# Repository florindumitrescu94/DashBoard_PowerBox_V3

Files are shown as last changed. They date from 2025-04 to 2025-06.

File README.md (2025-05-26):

# DashBoard PowerBox V3 

The third evolution of the DashBoard PowerBox project, upgraded based on personal experiences and others' suggestion.
It incorporates the same basic construction as the V2 box, with easily sourceable components, but adds a few new elements. 

## Separate DC Port control
This box is now capable of controling separate DC ports, with 3 of them having their own separate switches and another 2 linked to the same switch. 

## Always On DC Port
Also, I've included an "Always On" port, which passes through the current and voltage meters, so its' power consumption will be taken into account. 

## Isolated external control
I've added two optocouplers which can be used to control external equipment (see explanation below). Using optocouplers ensures good insulation between the Arduino and the external equipment, so that a malfunction of one does not affect the other. This feature will allow the control of external non-ASCOM connected equipment, like relays or other types of switches to control devices around the observatory. The case was not designed to incorporate any connectors for the External switches, but a 3.5mm mono audio jack is recommended. 

## PWM Automation based on ambiental condition without temperature probes
I've removed the two temperature probe leads, as, based on personal experience, I rarely used them and they seemd hit or miss. Now, the automation of the dew heaters is done based on temperature and dew point. (Using the dedicated Control Center app, you can set three levels of agressivity for the PWM automation. In NINA/APT, this automation is fixed on the "Mid" level.



## Dedicated Control Center App
You can now control the power box through a dedicated app, built to interface with the ASCOM Driver. This allows you to use the power box without using NINA or other sequencer software. This could be useful in case you want to use planetary imaging software, like SharpCap, which, usually, do not have any Switch control module. Also, inside the Control Center, you can toggle the automatic PWM function for each output separately and you can control the aggresivity of the Auto PWM in 3 steps. 


## Ability to rename each port
When opening the Setup Dialog, you can rename any PWM, DC or EXT port, so you can keep track of which port each device is plugged in.

## Choose what happens when you disconnect from the device
Iside the Setup Dialog, you can choose to keep the ports on or turn them off when disconnecting. There are three options, one for the DC ports, one for the External ports and one for the PWM ports. 

## Carry over port state settings between control computers
On disconnect, the Arduino will store the ports state inside the EEPROM and will retreive them when the device is reinitiated. 

## Improved case design
The case has been redesigned for easier assembly and mounting options. It now has a 1/4 20 photo thread built into the base and the screws that keep the box closed have been now relocated to the top of the lid, instead of on its' side. The walls of the case have been improved, as well, now being thicker and stronger. The case now sports labels for each input and output and little holes for LEDs under each DC Port, to easily identify if power is applied to the port. 

## Improved power efficiency
The circuit has, also, been redesigned to accomodate more switches and, in doing so, the switching MOSFETs have been updated to a more efficient version. The IRF5305 MOSFETS used in the V2 box have a Drain to Source resistance of 60mOhms when fully on (Resistance provided by the datasheet, with Vgs = 10V). I've now switched to using SUD50P04 MOSFETS, which have only 7.5 - to 10 mOhms (provided by datasheet, measured at Vgs = 10V, with Id = 24A). This will ensure very low losses through the circuit, even at high current draw. Each MOSFET is capable of sustaining 40A of current, however, each DC port is limited by a resettable fuse to 5 Amps, which should be plenty for most astro equipment. There is also an internal, alwasy on, unfused 12V connector, in case you might want to extract a 12V supply inside the box, for a small step-up/step-down converter for other accesories. 





All the extra complexity has increased the power boxes' size, from 80 x 55 to 100 x 80, but it is still keeping a small enough size to be easily mounted on any telescope. 

NOTE: When building the box, you can add a capacitor between the RST and GND pins of the Arduino, in order to keep it from resetting when connecting to the computer. If you do this, when programming the device, you will need to press the Reset button on the arduino when the IDE will get to the "Uploading" step.

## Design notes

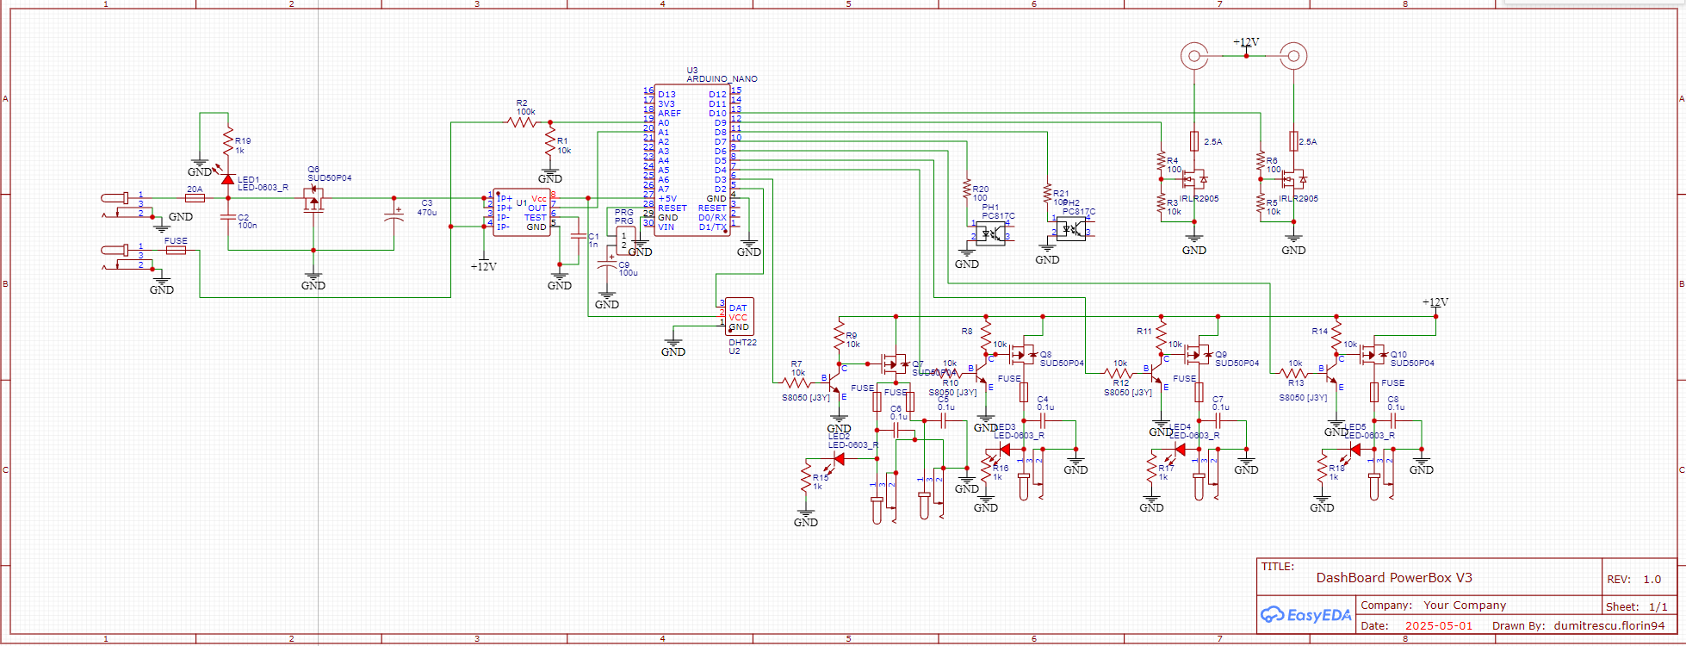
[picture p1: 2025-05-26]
Construction/schematic.png

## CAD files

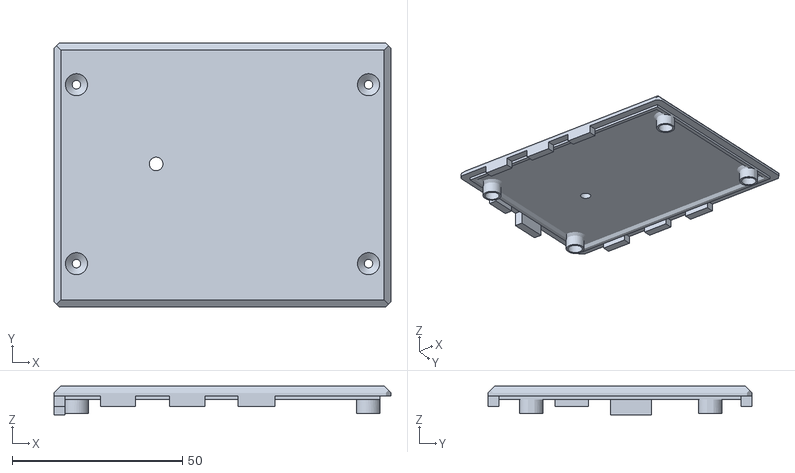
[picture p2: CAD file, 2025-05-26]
Construction/model/Cap.stl
99.0 x 77.5 x 8.50

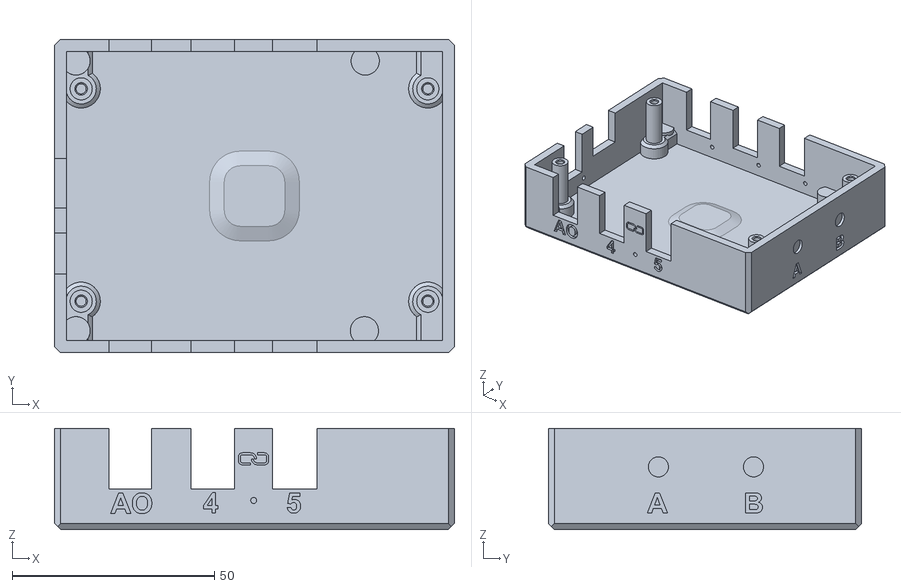
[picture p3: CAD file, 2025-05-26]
Construction/model/Body.stl
99.0 x 77.5 x 25.0

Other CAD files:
Construction/model/DashBoard_PowerBox_V3 v6.f3d
Construction/model/DashBoard_PowerBox_V3.f3d

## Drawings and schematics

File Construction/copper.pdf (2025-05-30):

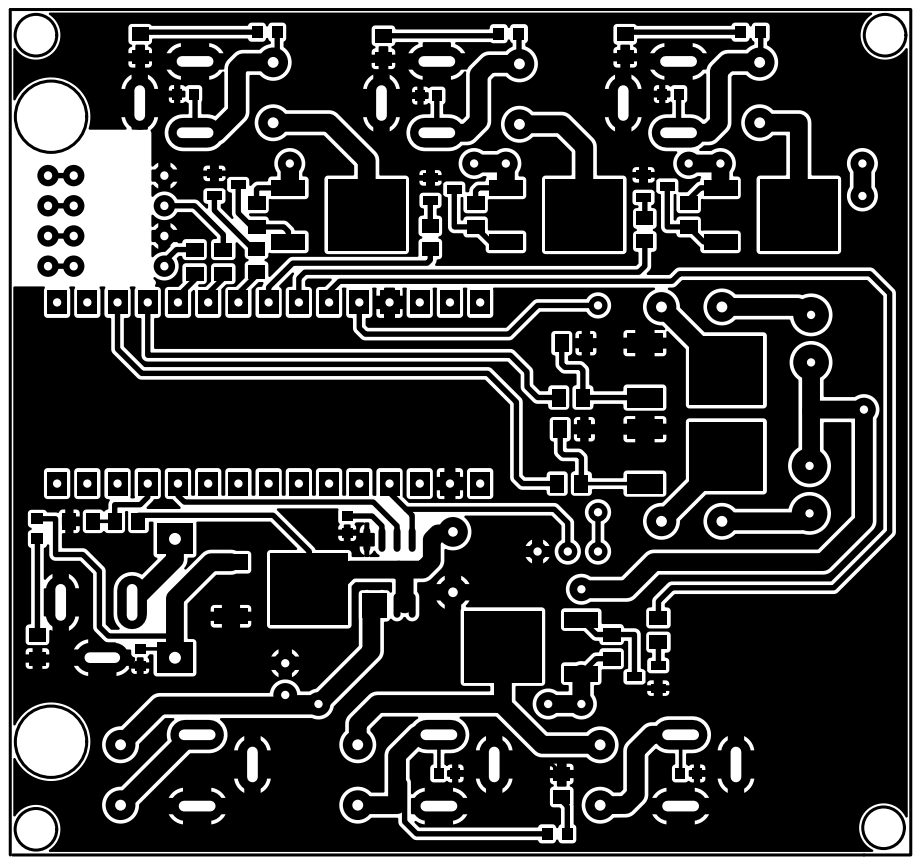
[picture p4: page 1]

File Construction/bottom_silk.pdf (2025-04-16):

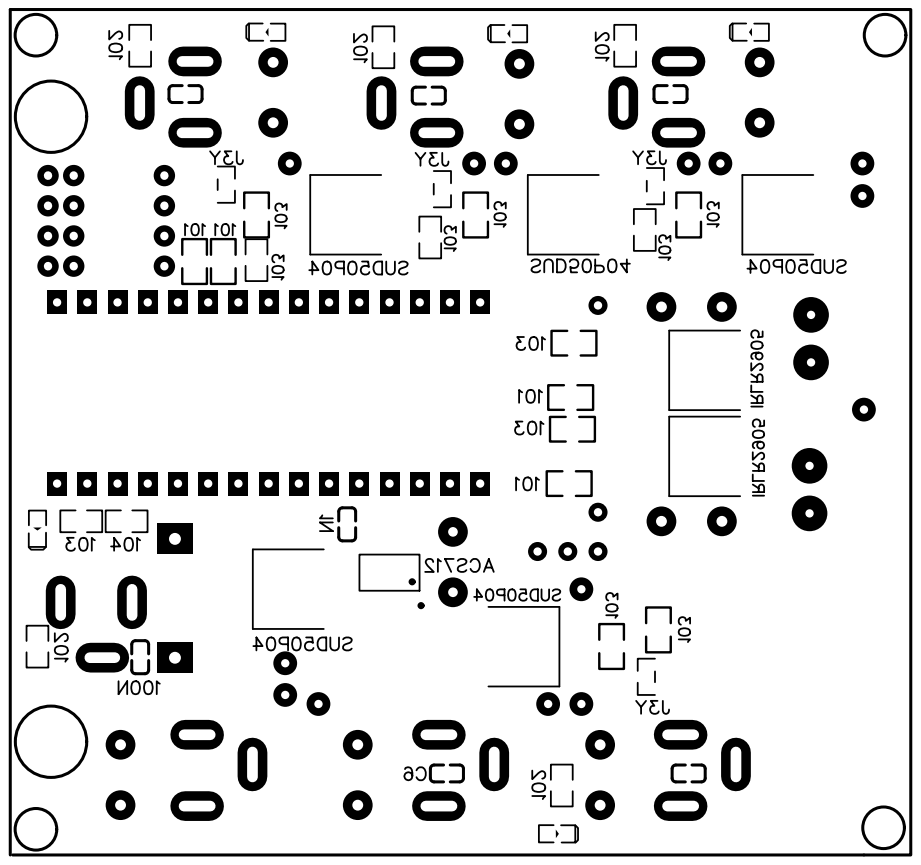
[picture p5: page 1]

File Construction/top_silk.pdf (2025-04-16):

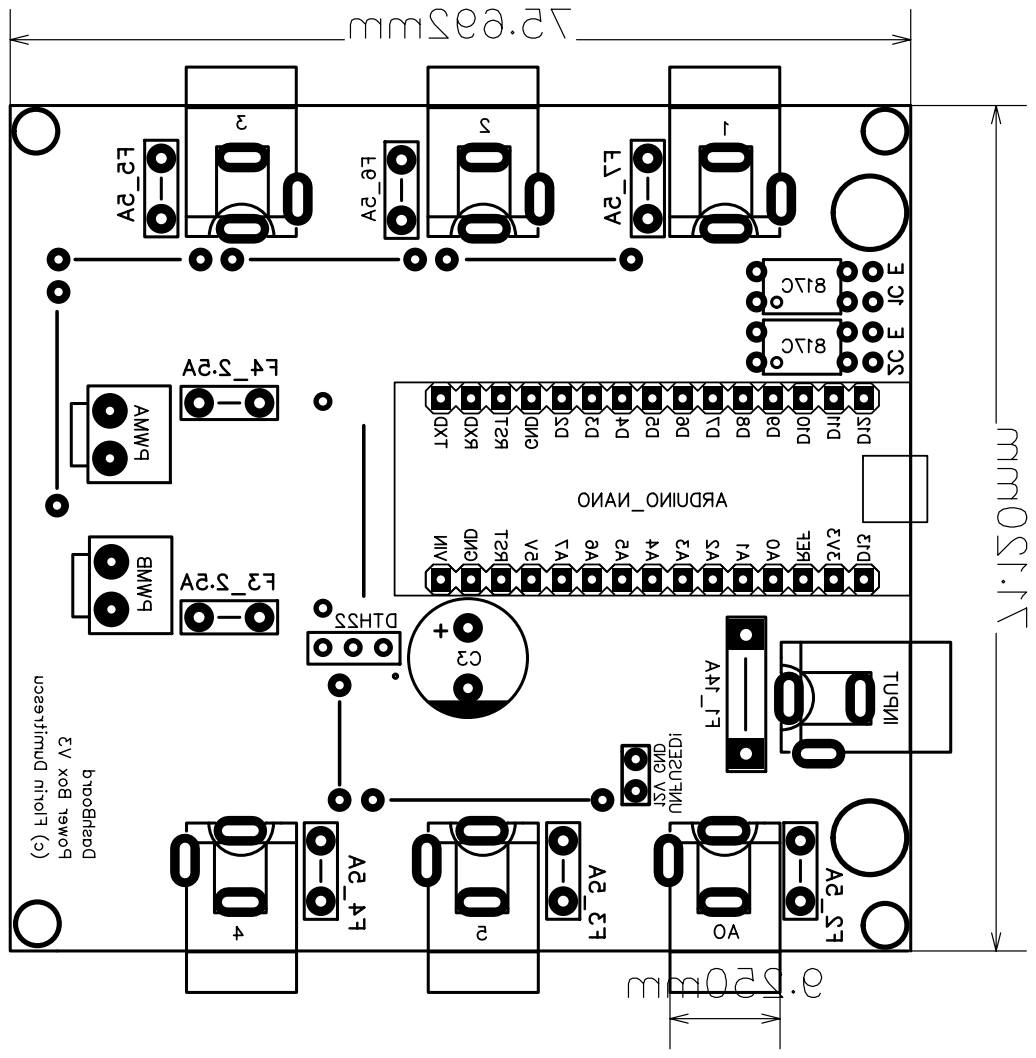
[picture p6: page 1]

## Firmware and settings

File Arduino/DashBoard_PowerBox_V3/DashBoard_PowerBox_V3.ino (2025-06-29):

/* Written by: Florin Dumitrescu
 *  for ascom_powerbox_and_ambientconditions built with
 *  Arduino NANO V3
 *  January 2024
 *  DashBoard Arduino code
 */
//INCLUDE LIBRARIES

#include <DHTStable.h>;
#include <EEPROM.h>;
DHTStable DHT;





//CODE VARIABLES
int DC1=0;
int DC2=0;
int DC3=0;
int DC45=0;
int EXT1=0;
int EXT2=0;
int PWM1=0;
int PWM2=0;
int level_a = 15; // MID by default
int level_b = 15; // MID by default
int levela_show = 1;
int levelb_show = 1;
int PWM_AUTO_A = 0;
int PWM_AUTO_B = 0;
float TEMP = 0.0;
int HUM_REL = 0;
float DEWPOINT = 0.0;
float DP_OFFSET = 2;
float VOLT = 0.00;
float VOLT_TEMP = 0.00;
int PIN_VALUE_A = 0;
int PIN_VALUE_V = 0;
float CURRENT_SAMPLE_SUM = 0.0;
int AVERAGE_COUNT = 0;
float AMP_AVERAGE[150];
float AVGAMP;
float AMP = 0.00;
float PWR = 0.00;
long int time1=0;
long int time2=0;
double PWR_TOTAL_S=0.00;
float PWR_TOTAL=0.00;
double ACS_resolution;


//VARIABLES FOR SERIALQUEUE
#define QUEUELENGTH         10             // number of commands that can be saved in the serial queue
#define MAXCOMMAND          42            // max length of a command
#define EOFSTR              '\n'
#define EOCOMMAND           '#'           // defines the end character of a command
#define SOCOMMAND           '>'           // defines the start character of a command
#define REFRESH             200           // read values every REFRESH milliseconds
#define PWMREFRESH          1000        // adjust PWM every 60 seconds
char* queue[QUEUELENGTH];
int queueHead = -1;
int queueCount = 0;
enum FSMStates { stateIdle, stateNtc, statePower, stateAutoPWM };
int idx = 0;                              // index into the command string
long int now;                             // now time in millis
long int last;                            // last time in millis
long int lastm;                           // last time we updated the dewheaters in millis
String line;                              // command buffer


//CHANGE ACS_VARIANT WITH YOUR ACS CHIP VARIANT (5A, 20A, 30A)
const int ACS_Variant = 20; //A
//PINS
const int DC1_PIN = 4 ;
const int DC2_PIN = 5;
const int DC3_PIN = 6;
const int DC45_PIN = 3;
const int EXT1_PIN = 7;
const int EXT2_PIN = 8;
const int PWM1_PIN = 10;
const int PWM2_PIN = 9;
const int DHT22_DATA = 2;
const int VM = A0;
const int AM = A1;


//-----------------------------------------------------------------------
// Utility functions
//-----------------------------------------------------------------------

char* pop() {
  --queueCount;
  return queue[queueHead--];
}


void push(char command[MAXCOMMAND]) {
  queueCount++;
  queueHead++;
  strncpy(queue[queueHead], command, MAXCOMMAND);
}


//ARDUINO INITIALIZATION
void setup()
{
  //SET PIN MODES
    pinMode(DC1_PIN, OUTPUT);
    pinMode(DC2_PIN, OUTPUT);
    pinMode(DC3_PIN, OUTPUT);
    pinMode(DC45_PIN, OUTPUT);
    pinMode(PWM1_PIN, OUTPUT);
    pinMode(PWM2_PIN, OUTPUT);
    pinMode(EXT1_PIN, OUTPUT);
    pinMode(EXT2_PIN, OUTPUT);
    pinMode(DHT22_DATA, INPUT);
    pinMode(VM, INPUT);
    pinMode(AM, INPUT);


  //INITIALIZE PIN STATE FROM EEPROM
   //
   if (EEPROM.read(40) != 255)
   // eerpom initializes with 255 on all values on a fresh arduino. That throws off ASCOM driver. 
   //To fix this, we check address 40 to see if it is 255. That means this is a first boot for the arduino. 
   //It skips the values, setting them to 0 as in the variable declaration step.
   //We then set the address 40 to 1 so that next time, we know it is not a first run and the EEPROM can be read
   {
    DC1=EEPROM.read(3);
    DC2=EEPROM.read(4);
    DC3=EEPROM.read(5);
    DC45=EEPROM.read(6);
    EXT1=EEPROM.read(7);
    EXT2=EEPROM.read(8);
    level_a=EEPROM.read(9);
    level_b=EEPROM.read(10);
    PWM1=EEPROM.read(1);
    PWM2=EEPROM.read(2);
   }
   EEPROM.update(40,1);//on first run on a fresh arduino, update address 40 to 1, so it will run the eeprom reads
    digitalWrite(DC1_PIN,DC1);
    digitalWrite(DC2_PIN,DC2);
    digitalWrite(DC3_PIN,DC3);
    digitalWrite(DC45_PIN,DC45);
    digitalWrite(EXT1_PIN,EXT1);
    digitalWrite(EXT2_PIN,EXT2);
    analogWrite(PWM1_PIN,PWM1);
    analogWrite(PWM2_PIN,PWM2);

    for ( int i=0; i < QUEUELENGTH; i++)
      queue[i] = (char*)malloc(MAXCOMMAND);
    line.reserve(MAXCOMMAND);
    
    Serial.begin(115200);
    Serial.flush();

    switch (ACS_Variant){
      case 5: 
        ACS_resolution = 0.185;
        break;
      case 20: 
        ACS_resolution = 0.100;
        break;
      case 30:
        ACS_resolution = 0.066;
        break;
    }
    // initialize our delays
    now = millis();
    last = now;
    lastm = now;
}

void clearSerialPort() {
  while ( Serial.available() )
    Serial.read();
}

// SerialEvent occurs whenever new data comes in the serial RX.
// you should really consider a start of command character.
void serialEvent() {

  // '#' ends the command, do not store these in the command buffer
  // read the command until the terminating # character
  char buf[MAXCOMMAND];
  while ( Serial.available() )
  {
    char inChar = Serial.read();
    switch ( inChar )
    {
      case '>':     // soc, reinit line
        // memset(line, 0, MAXCOMMAND);
        line = "";
        idx = 0;
        break;
      case '#':     // eoc
        line.toCharArray(buf, MAXCOMMAND);
        idx = 0;
        push(buf);
        break;
      default:      // anything else
        if ( idx < MAXCOMMAND - 1) {
          line += inChar;
        }
        break;
    }
  }
}


void processSerialCommand() {
  // this should never happen
  if ( queueCount == 0 )
    return;

  String cmd = String(pop());


//READS AND EXECUTES SERIAL COMMANDS FROM ASCOM DRIVER
  if (cmd.substring(0,6) == "SETDC1") SET_DC_PIN(1,(cmd.substring((cmd.indexOf('_')+1),cmd.indexOf('_')+2)).toInt()); 
  else if (cmd.substring(0,6) == "SETDC2") SET_DC_PIN(2,(cmd.substring((cmd.indexOf('_')+1),cmd.indexOf('_')+2)).toInt());
  else if (cmd.substring(0,6) == "SETDC3") SET_DC_PIN(3,(cmd.substring((cmd.indexOf('_')+1),cmd.indexOf('_')+2)).toInt()); 
  else if (cmd.substring(0,6) == "SETDC4") SET_DC_PIN(4,(cmd.substring((cmd.indexOf('_')+1),cmd.indexOf('_')+2)).toInt());  
  else if (cmd.substring(0,7) == "SETEXT1") SET_EXT_PIN(1,(cmd.substring((cmd.indexOf('_')+1),cmd.indexOf('_')+2)).toInt()); 
  else if (cmd.substring(0,7) == "SETEXT2") SET_EXT_PIN(2,(cmd.substring((cmd.indexOf('_')+1),cmd.indexOf('_')+2)).toInt()); 
  else if (cmd == "SETAUTOPWMA_1") {
      PWM_AUTO_A = 1;
  }
  else if (cmd == "SETAUTOPWMA_0") {
    PWM_AUTO_A = 0;
  }
  else if (cmd == "SETAUTOPWMB_1") {
      PWM_AUTO_B = 1;
  }
  else if (cmd == "SETAUTOPWMB_0") {
    PWM_AUTO_B = 0;
  }
  else if (cmd.substring(0,9) == "SETLEVELA") {SET_LEVEL(1,(cmd.substring((cmd.indexOf('_')+1),cmd.indexOf('_')+2)).toInt()); EEPROM.update(9,level_a);}
  else if (cmd.substring(0,9) == "SETLEVELB") {SET_LEVEL(2,(cmd.substring((cmd.indexOf('_')+1),cmd.indexOf('_')+2)).toInt()); EEPROM.update(10,level_b);}
  else if (cmd == "READEEPROM") //reads existing PWM1 and 2 values from EEPROM and sets them on PWM1 and 2 on connection
  {
    PWM1=EEPROM.read(1);
    PWM2=EEPROM.read(2);
    SET_PWM_POWER(1,PWM1);
    SET_PWM_POWER(2,PWM2);
  }
  
  else if (cmd.substring(0,7) == "SETPWM1") SET_PWM_POWER(1,cmd.substring((cmd.indexOf('_')+1),(cmd.indexOf('_')+4)).toInt());
  else if (cmd.substring(0,7) == "SETPWM2") SET_PWM_POWER(2,cmd.substring((cmd.indexOf('_')+1),(cmd.indexOf('_')+4)).toInt());
  else if (cmd == "REFRESH")
  {
    Serial.print(DC1); //0
    Serial.print(":");
    Serial.print(DC2); //1
    Serial.print(":");
    Serial.print(DC3); //2
    Serial.print(":");
    Serial.print(DC45); //3
    Serial.print(":");
    Serial.print(PWM1); //4
    Serial.print(":");
    Serial.print(PWM2); //5
    Serial.print(":");
    Serial.print(TEMP); //6
    Serial.print(":");
    Serial.print(HUM_REL); //7
    Serial.print(":");
    Serial.print(DEWPOINT); //8
    Serial.print(":");
    Serial.print(VOLT); //9
    Serial.print(":");
    Serial.print(AMP); //10
    Serial.print(":");
    Serial.print(PWR); //11
    Serial.print(":");
    Serial.print(PWR_TOTAL); //12
    Serial.print(":");
    Serial.print(PWM_AUTO_A); //13
    Serial.print(":");
    Serial.print(PWM_AUTO_B); //14
    Serial.print(":");
    Serial.print(levela_show); //15
    Serial.print(":");
    Serial.print(levelb_show); //16
    Serial.print(":");
    Serial.print(EXT1); //17
    Serial.print(":");
    Serial.print(EXT2); //18
    Serial.print("#");
  }
}


//LOOP TO READ SERIAL COMMANDS
void loop()
{
  GET_POWER(); //needs to run constantly for correct calculations
  static byte FSMState = stateIdle;

  if ( queueCount >= 1 ) {               // check for serial command
    processSerialCommand();
  }

  switch (FSMState) {
    case stateIdle:
      // wait REFRESH milliseconds between Read cycles
      now = millis();
      if ( now > last + REFRESH )
        FSMState = statePower;
      else
        FSMState = stateIdle;
      break;
    case statePower:
      GET_AMBIENT();
      now = millis();
      FSMState = stateAutoPWM;
      last = now;
      break;
    case stateAutoPWM:
      now = millis();
      if ( now > lastm + PWMREFRESH ) {
        RUN_AUTO_PWM_A();
        RUN_AUTO_PWM_B();
        lastm = now;
      }
      last = now;
      FSMState = stateIdle;
      break;
  }
} 
// END loop


//SET/GET FUNCTIONS


//SET DC PIN

void SET_DC_PIN(int pin, int state){
     if (state == 0)
     { 
       if (pin == 1) 
       {
        digitalWrite(DC1_PIN, LOW);
        DC1 = 0;
       }
       else if (pin == 2) 
       {
        digitalWrite(DC2_PIN, LOW);
        DC2 = 0;
       }
       else if (pin == 3) 
       {
        digitalWrite(DC3_PIN, LOW);
        DC3 = 0;
       }
       else if (pin == 4) 
       {
        digitalWrite(DC45_PIN, LOW);
        DC45 = 0;
       }
       }
      else if (state == 1) 
      {
       if (pin==1) 
       {
        digitalWrite(DC1_PIN, HIGH);
        DC1 = 1;
       }
       else if (pin == 2) 
       {
        digitalWrite(DC2_PIN, HIGH);
        DC2 = 1;
       }
       else if (pin == 3) 
       {
        digitalWrite(DC3_PIN, HIGH);
        DC3 = 1;
       }
       else if (pin == 4) 
       {
        digitalWrite(DC45_PIN, HIGH);
        DC45 = 1;
       }
      }
      if (pin == 1) EEPROM.update(3,DC1);
      else if (pin == 2) EEPROM.update(4,DC2);
      else if (pin == 3) EEPROM.update(5,DC3);
      else if (pin == 4) EEPROM.update(6,DC45);
}
//END SET DC PIN



// SET EXT PIN
void SET_EXT_PIN(int pin, int state){
     if (state == 0)
     { 
       if (pin == 1) 
       {
        digitalWrite(EXT1_PIN, LOW);
        EXT1 = 0;
         
       }
       else if (pin == 2) 
       {
        digitalWrite(EXT2_PIN, LOW);
        EXT2 = 0;
        
       }
       }
      else if (state == 1) 
      {
       if (pin==1) 
       {
        digitalWrite(EXT1_PIN, HIGH);
        EXT1 = 1;
        
       }
       else if (pin == 2) 
       {
        digitalWrite(EXT2_PIN, HIGH);
        EXT2 = 1;
        
       }
      }
    EEPROM.update(7,EXT1);
    EEPROM.update(8,EXT2);
}
//END SET EXT PIN



//SET PWM POWER
void SET_PWM_POWER(int pwmno,int state) {
    int pwm_value = (state*255)/100;
    if (pwmno == 1)
    {
    analogWrite(PWM1_PIN, pwm_value);
    PWM1 = state;
    }
    else if (pwmno == 2)
    {
    analogWrite(PWM2_PIN, pwm_value);
    PWM2 = state;
    }
    EEPROM.update(1,PWM1);
    EEPROM.update(2,PWM2);
}
//END SET PWM POWER





// RUN PWM AUTO 
void RUN_AUTO_PWM_A() {
  if (PWM_AUTO_A == 1)
  {
    double delta_td = TEMP-DEWPOINT;
    int delta_t = round(delta_td);
    if (delta_t <= 10)
    {
      int pwm_val = (10-delta_t) * level_a;
      if (pwm_val >=100)
      {
        pwm_val = 100;
      }
     SET_PWM_POWER(1,pwm_val);
     //SET_PWM_POWER(2,pwm_val);
    }
    else 
    {
      SET_PWM_POWER(1,0);
      //SET_PWM_POWER(2,0);
    }
  }
}
void RUN_AUTO_PWM_B()
{
  if (PWM_AUTO_B == 1)
  {
    double delta_td = TEMP-DEWPOINT;
    int delta_t = round(delta_td);
    if (delta_t <= 10)
    {
      int pwm_val = (10-delta_t) * level_b;
      if (pwm_val >=100)
      {
        pwm_val = 100;
      }
     SET_PWM_POWER(2,pwm_val);

    }
    else 
    {
      SET_PWM_POWER(2,0);

    }
  }
}
//END SET AUTO PWM POWER





//MEASURE AND CALCULATE POWER USAGE
  void GET_POWER() {
    time1=millis();
    if (AVERAGE_COUNT == 150) AVERAGE_COUNT = 0;
    float VOLTAGE_SAMPLE_SUM=0;
    for (int v=0;v<150;v++) 
    {
      PIN_VALUE_V =  analogRead(VM);
      VOLTAGE_SAMPLE_SUM +=PIN_VALUE_V;     
    }
    VOLTAGE_SAMPLE_SUM /=150;
    VOLT_TEMP = (VOLTAGE_SAMPLE_SUM * 5.0) / 1024.0;   
    VOLT = VOLT_TEMP / 0.0894;        
    if (VOLT < 0.1) VOLT=0.0;    
    CURRENT_SAMPLE_SUM=0;
    for (int i=0;i<150;i++)
    {
      PIN_VALUE_A= analogRead(AM);
      CURRENT_SAMPLE_SUM = CURRENT_SAMPLE_SUM + PIN_VALUE_A;
    }
    AMP_AVERAGE[AVERAGE_COUNT] = (2.494 - ((CURRENT_SAMPLE_SUM/150)*(5.0/1024.0))) / ACS_resolution;
    AVGAMP=0;
    for (int c=0;c<150;c++) AVGAMP += AMP_AVERAGE[c];
    AMP = (AVGAMP*-1)/150;
    if (AMP< 0.01) AMP=0.0;
    PWR_TOTAL_S = PWR_TOTAL_S + ((((PWR+(VOLT*AMP))/2)*(time1-time2))/1000); // total power in W*s between cycles
    PWR = VOLT * AMP;
    AVERAGE_COUNT = AVERAGE_COUNT + 1;
    time2=millis();
    PWR_TOTAL_S = PWR_TOTAL_S + ((PWR*(time2-time1))/1000); // total power in W*s
    PWR_TOTAL = PWR_TOTAL_S/3600;  // Total power used in W*h                      
    //Serial.println(AVGAMP);             
}
//END GET POWER USAGE



//GET AMBIENT CONDITIONS
  void GET_AMBIENT() {
  int PIN_VALUE_T = DHT.read22(DHT22_DATA);
   HUM_REL = DHT.getHumidity();
   TEMP = DHT.getTemperature();
   DEWPOINT  = (TEMP - (100 - HUM_REL) / 5);
 }
 
 
 
 
 //CORRECT PWM VALUE
 void SET_PWM_VALUE(int pwmno, int value){
  value = CORRECT_PWM(value);
  int pwm_pin = (value*255)/100;
  if (pwmno == 1) analogWrite (PWM1, pwm_pin);
  if (pwmno == 2) analogWrite (PWM2, pwm_pin);
 }
 int CORRECT_PWM(int state){
 if (state > 100) return 100;
 if (state < 0) return 0;
 else return state;
}

void SET_LEVEL(int port, int level)
{
  int convert;
  if (level == 1) convert = 10;
  else if (level == 2) convert = 15;
  else if (level == 3) convert = 20; 
  if (port == 1) {level_a = convert; levela_show = level;}
  if (port == 2) {level_b = convert; levelb_show = level;}
}
 

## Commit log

2025-04-16 added ino code, case models and pcb
    [Body.stl, Cap.stl, DashBoard_PowerBox_V3.f3d]
2025-05-02 Added driver profile for switch states, as well
2025-05-02 Update DashBoard_PowerBox_V3.ino
    added reading and writing pwm 1 and 2 values to eeprom
2025-05-08 Corrected arduino code
2025-05-25 Fixed Arduino freezing when receiving "get" commands
    Now REFRESH only happens then GetSwitch(0) or GetSwitchValue(0) are called. REFRESH sends all values separated by ":", then the driver stores the individual values into an array. When GetSwitch or GetSwitchValue is called, values are read directly from the array. The array refreshes every [device polling interval] seconds (in NINA) or every 5 seconds when using the app.
    [DashBoard_PowerBox_V3.ino]
2025-05-26 Changed "PCB" folder name to "Construction"
    [Body.stl, Cap.stl, DashBoard_PowerBox_V3.f3d]
2025-05-26 Added PWM automation in NINA with 3 levels
2025-05-26 updated models with enlarged USB port slot and reset switch hole,
    [Body.stl, Cap.stl, DashBoard_PowerBox_V3 v6.f3d]
2025-06-12 Updated arduino code for fresh arduinos
    Updated code to check if first run (EEPROM initializes with 255 on all values on a fresh arduino). Added logic to check for fresh board and update address 40 to signal a first run
